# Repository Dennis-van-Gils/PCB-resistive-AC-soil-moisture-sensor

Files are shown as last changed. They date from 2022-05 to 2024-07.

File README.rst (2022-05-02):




Resistive AC soil moisture sensor
=================================

This project involves a printed circuit board design to measure the resistance
between two metallic probes that can be placed inside soil as a measure of the
soil humidity. It uses AC current to sense the resistance between the probes,
preventing corrosion of the probes which otherwise would happen when a DC
current is used instead. The design is based on the
`SMX sensor <https://www.emesystems.com/smx/main.html>`__ by EME Systems.

The sensor can be supplied with either 3.3 V or 5.0 V and utilizes an onboard
3.0 V regulator powering a TLC555 timer. The output is a pulse train with an
amplitude equal to the supply voltage and of a variable frequency that
correlates to the measured resistance. The pulses are at a 50% duty cycle.

Contains EAGLE, Fusion360 and LTSpice project files.

- Github: https://github.com/Dennis-van-Gils/PCB-resistive-AC-soil-moisture-sensor

PCB design
==========

The PCB production Gerber files can be found `here. <EAGLE/AC_soil_sensor_v1.0_2022-05-01.zip>`__

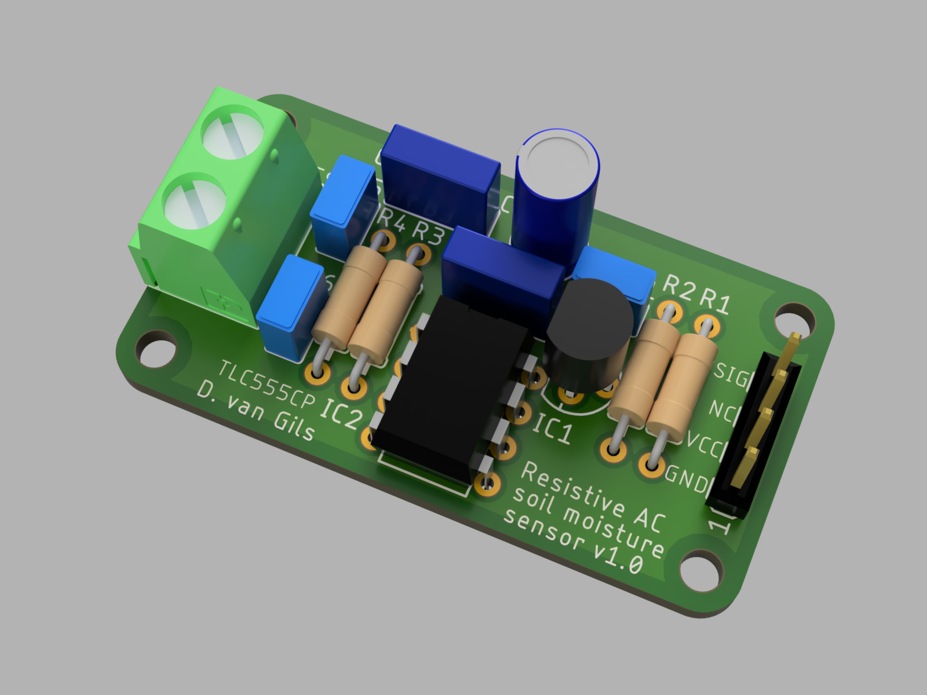
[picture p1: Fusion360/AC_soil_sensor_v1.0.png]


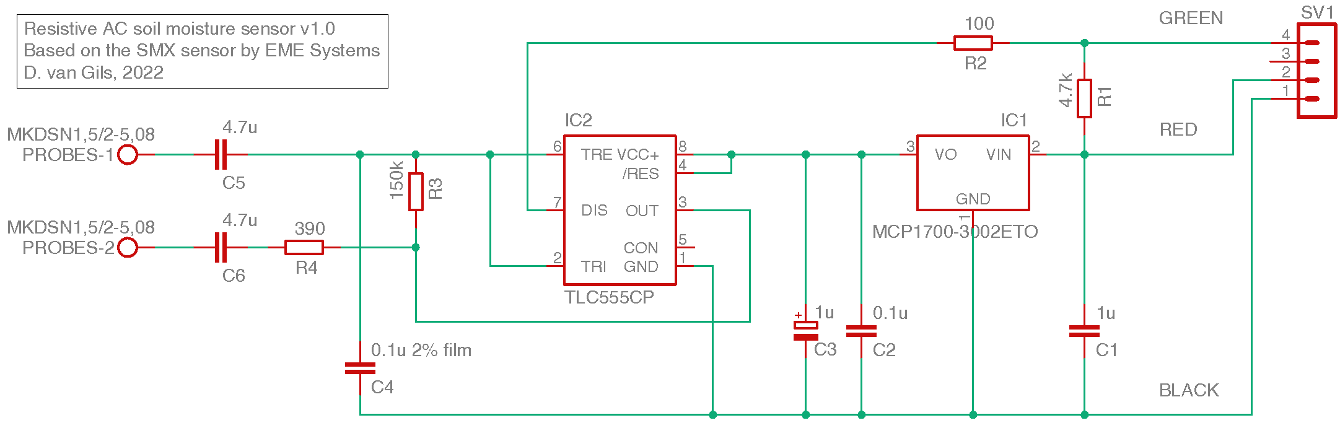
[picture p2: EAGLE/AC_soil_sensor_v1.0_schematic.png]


Bill of materials
=================

+-----+-------------------+--------------------------------------+------------------------------------+
| IC1 | CMOS low-dropout voltage regulator, 3.0V 250mA           | MCP1700-3002E/TO                   |
+-----+-------------------+--------------------------------------+------------------------------------+
| IC2 | CMOS 555 timer, input 2V-15V                             | TLC555CP                           |
+-----+-------------------+--------------------------------------+------------------------------------+
| R1  | 4.7 kΩ  1/4W   5% | Resistor, carbon film                |                                    |
+-----+-------------------+--------------------------------------+------------------------------------+
| R2  | 100  Ω  1/4W   5% | Resistor, carbon film                |                                    |
+-----+-------------------+--------------------------------------+------------------------------------+
| R3  | 150 kΩ  1/4W   5% | Resistor, carbon film                |                                    |
+-----+-------------------+--------------------------------------+------------------------------------+
| R4  | 390  Ω  1/4W   5% | Resistor, carbon film                |                                    |
+-----+-------------------+--------------------------------------+------------------------------------+
| C1  | 1   μF   50V  10% | Capacitor, ceramic                   | KEMET C320C105K5N5TA91707301       |
+-----+-------------------+--------------------------------------+------------------------------------+
| C2  | 0.1 μF   50V  10% | Capacitor, ceramic                   | KEMET C320C104K5R5TA7301           |
+-----+-------------------+--------------------------------------+------------------------------------+
| C3  | 1   μF   50V      | Capacitor, aluminium electrolytic    |                                    |
+-----+-------------------+--------------------------------------+------------------------------------+
| C4  | 0.1 μF   63V   5% | Capacitor, metallized polyester film | TDK B32529C0104J                   |
+-----+-------------------+--------------------------------------+------------------------------------+
| C5  | 4.7 μF   25V  10% | Capacitor, ceramic                   | KEMET C320C475K3N5TA91707301       |
+-----+-------------------+--------------------------------------+------------------------------------+
| C6  | 4.7 μF   25V  10% | Capacitor, ceramic                   | KEMET C320C475K3N5TA91707301       |
+-----+-------------------+--------------------------------------+------------------------------------+

LTspice simulation
==================

The frequency-resistance relationship of the simulated idealized circuit:

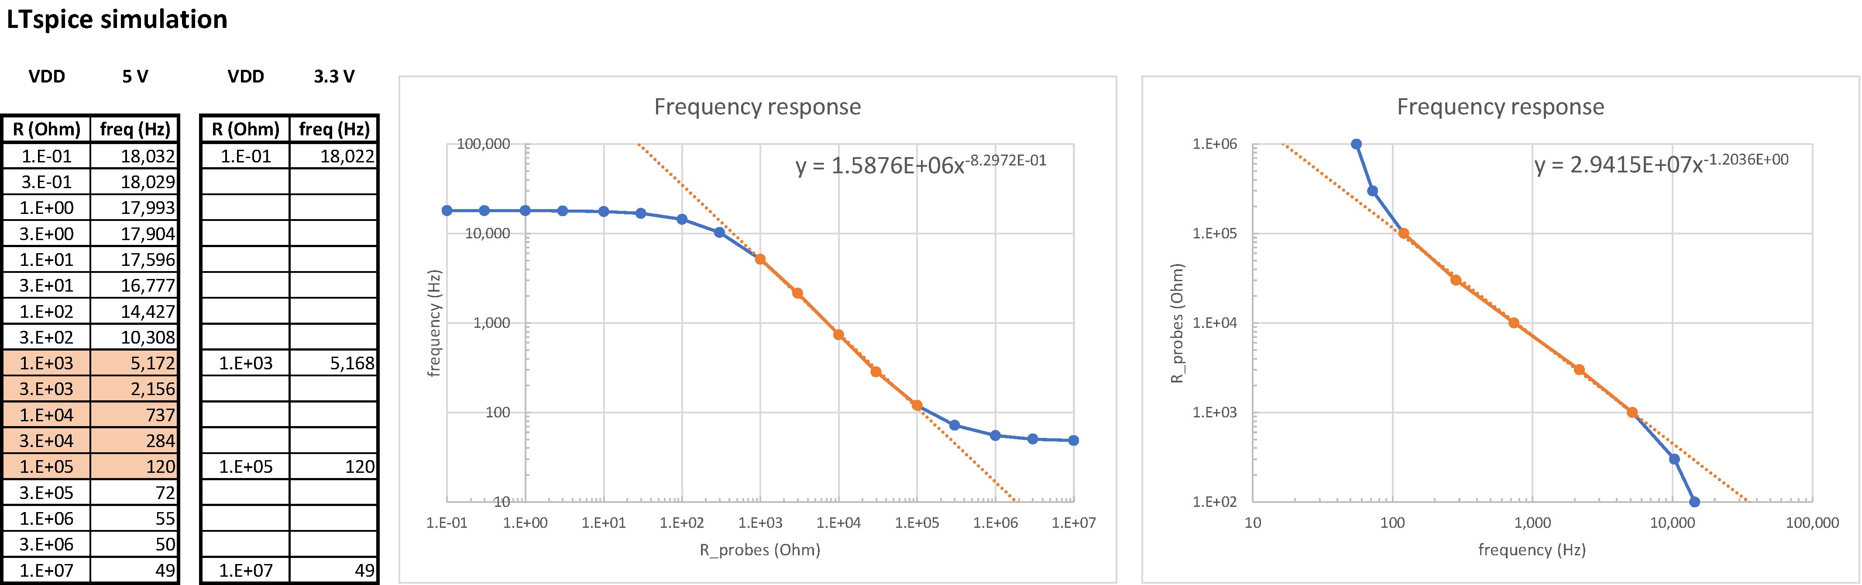
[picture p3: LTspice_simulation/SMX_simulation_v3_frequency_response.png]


Dennis van Gils, 2022

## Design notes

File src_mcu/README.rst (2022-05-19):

Demo C++ source code to be flashed onto a microcontroller board:

Minimum working example to measure a frequency on a digital input pin using
an interrupt service routine and with averaging applied to the frequency
measurement.

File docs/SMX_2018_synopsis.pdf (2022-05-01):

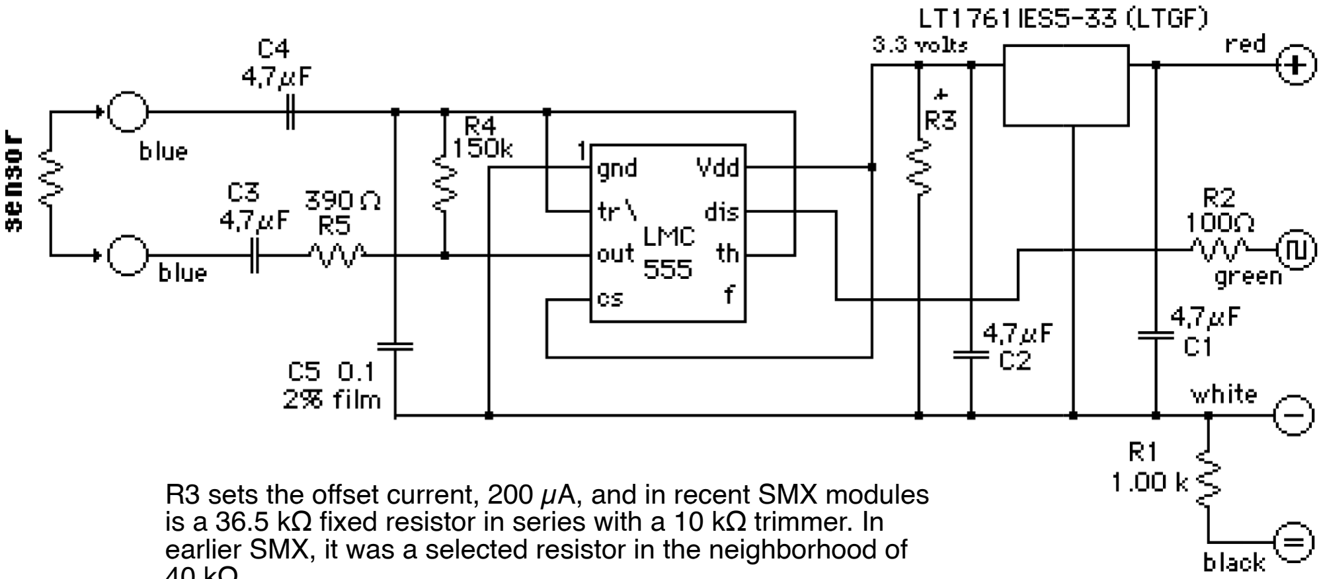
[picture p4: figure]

R3 sets the offset current, 200 µA, and in recent SMX modules is a 36.5 kΩ fixed resistor in series with a 10 kΩ trimmer. In earlier SMX, it was a selected resistor in the neighborhood of 40 kΩ.

The power supply voltage is regulated at 3.3 volts DC by the micropower regulator. The power supply + input can be as low as 4 volts and as high as 15 volts. Filter capacitors are provided for stability and averaging of the supply current. The LMC555 timer operates in its direct feedback mode, with a square wave on the totem pole output from pin 3 charging or discharging the 0.1 µF polyester film timing capacitor through the network of fixed resistors in series/parallel with the moisture sensor. When the sensor is dry, the 150 kΩ resistor sets a minimum oscillator frequency of 50 hertz. When the sensor is wet, or a short circuit, the 390 Ω in series with the grid limits the upper frequency to about 13 kHz. The current through the sensing grid is AC. Nonpolar ceramic capacitors isolate the circuit from the sensor, to assure that the average current is AC and to forestall galvanic interactions in the soil environment. The output frequency is transmitted to the logger from the open collector DIS output pin, protected from miswiring by the 100 Ω resistor. Normally a pullup resistor will be provided to give voltage transitions at the logger. The current drawn by the circuit varies linearly with the frequency due to the charge and discharge cycles of the 0.1 µF capacitor. The supply current is proportional to wetness, a voltage signal can be taken from across the 1kΩ resistor. The offset current is set to 200 µA by R3, 36.5 kΩ in series with 10 kΩ trimmer.
There will be a small AC component on the DC output signal, that can be averaged in software. A 10 µF capacitor in parallel with the output resistor will reduce the AC component to <5 millivolts.

black

white | frequency output
| common

3.3 – 15 V
red | 0.2 – 1 mA
green

4.7 kΩ

sensor

SMX

I. Digital frequency output: 50 – 10,000 Hz.

black

white

voltage signal (+)
0.2 – 1 V DC

common

4.5 – 15 V
red | 0.2 – 1 mA

100 µF

sensor

SMX | green

II. Voltage output: 0.2 – 1 V.

black

white

voltage signal (+)
Vout = I * R

common

4.5 – 15 V
red | 0.2 – 1 mA

22 µF

0.2 ~ 1 mA

sensor

green

R

SMX

III. Two wire current output: 0.2 – 1 mA.

The current on the two wire circuit may be converted to a voltage at the input of the data logger. A 1 kΩ resistor will convert the 0.2 – 1 mA current into a 0.2 – 1 V signal.

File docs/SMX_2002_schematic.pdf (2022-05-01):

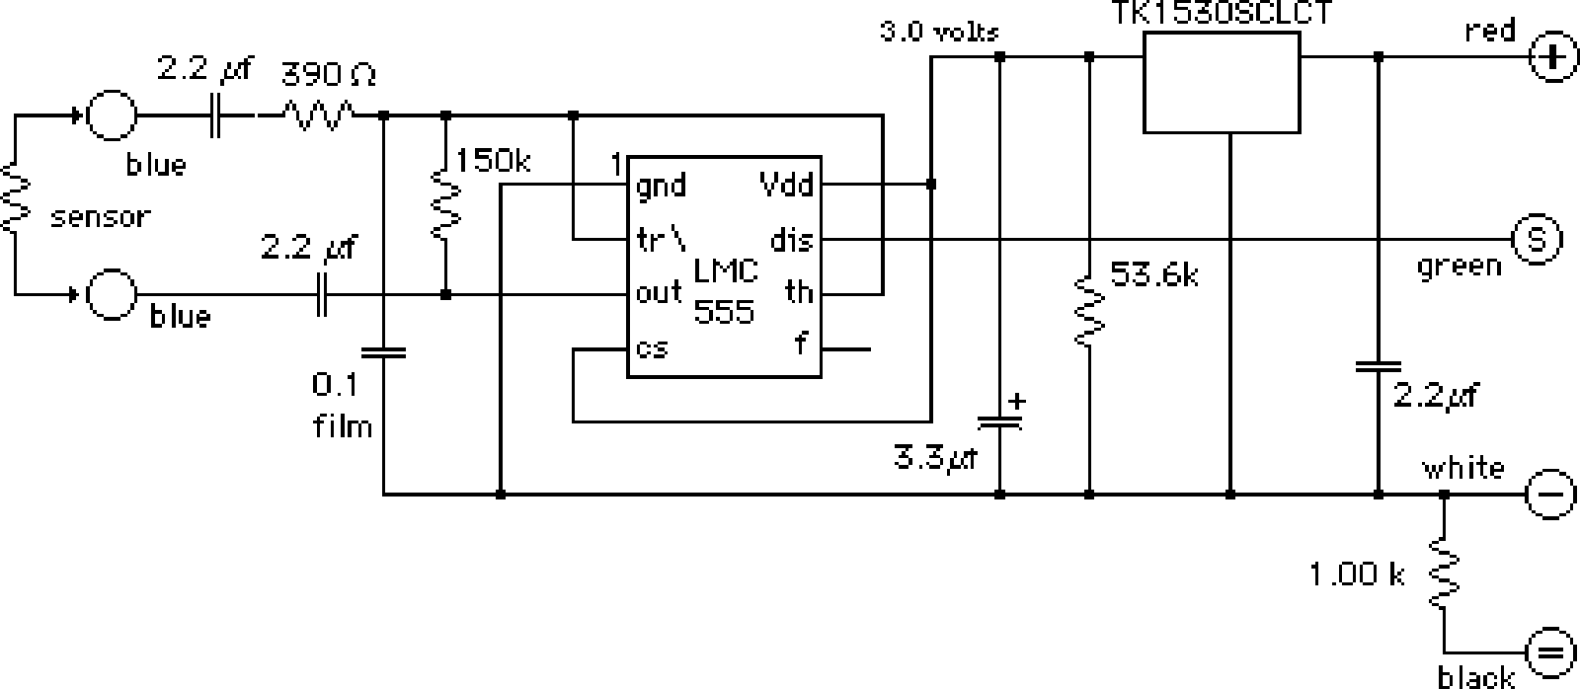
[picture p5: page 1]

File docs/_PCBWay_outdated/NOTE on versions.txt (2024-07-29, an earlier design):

Notes:
* Even though the board in this folder is called v2, it is not. It is an alpha version. Alpha 2.0 that is. The version in the folder one up is labelled 1, as in release 1.0.
* v2d v18 equals v2f

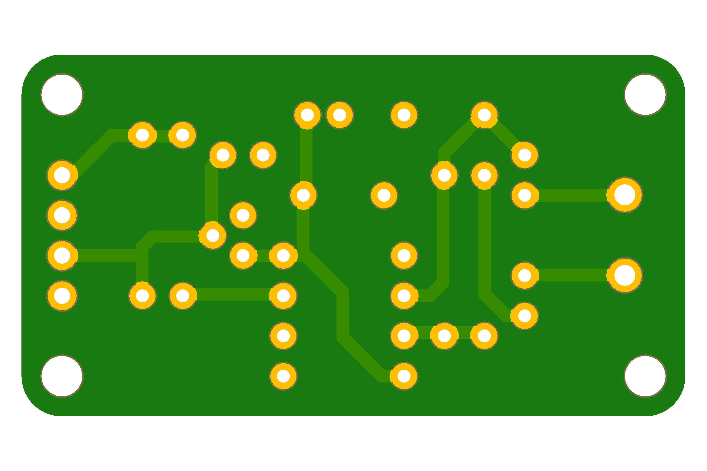
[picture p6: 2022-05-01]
EAGLE/AC_soil_sensor_v1.0_bottom.png

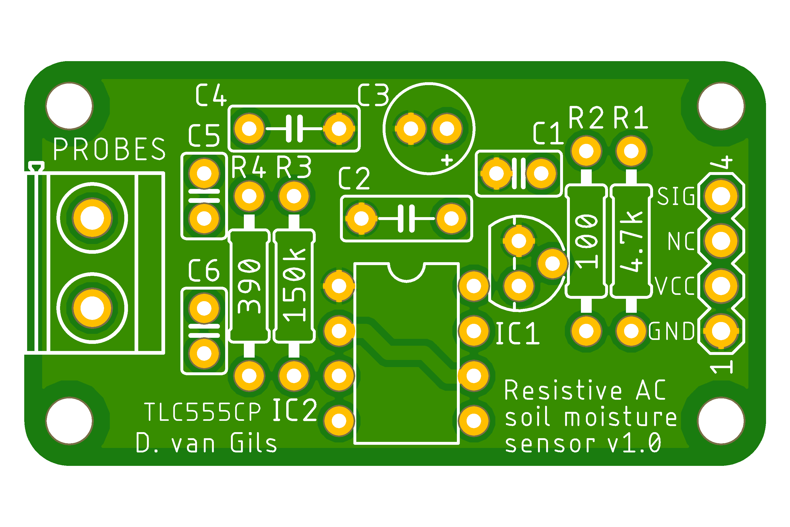
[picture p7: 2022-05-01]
EAGLE/AC_soil_sensor_v1.0_top.png

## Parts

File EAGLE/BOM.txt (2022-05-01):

Bill of materials: `Resistive AC soil moisture sensor v1.0`

IC1   MCP1700-3002E/TO     CMOS low dropout voltage regulator, output 3.0V 250mA, input 2.3V-6.0V
IC2   TLC555CP             CMOS 555 timer, input 2V-15 V
R1    4.7 kΩ  1/4W   5%    Resistor, carbon film
R2    100  Ω  1/4W   5%    Resistor, carbon film
R3    150 kΩ  1/4W   5%    Resistor, carbon film
R4    390  Ω  1/4W   5%    Resistor, carbon film
C1    1   μF   50V  10%    Capacitor, ceramic                     KEMET C320C105K5N5TA91707301
C2    0.1 μF   50V  10%    Capacitor, ceramic                     KEMET C320C104K5R5TA7301
C3    1   μF   50V         Capacitor, aluminium electrolytic
C4    0.1 μF   63V   5%    Capacitor, metallized polyester film   TDK B32529C0104J
C5    4.7 μF   25V  10%    Capacitor, ceramic                     KEMET C320C475K3N5TA91707301
C6    4.7 μF   25V  10%    Capacitor, ceramic                     KEMET C320C475K3N5TA91707301

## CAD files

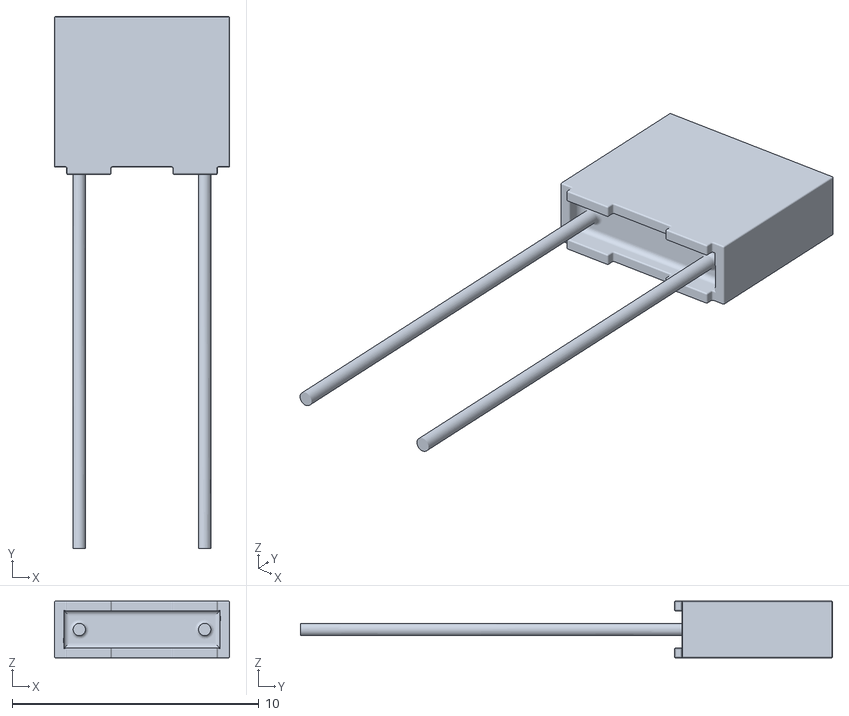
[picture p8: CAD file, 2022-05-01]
Fusion360/3D_parts/47nF Film Capacitor MKT.STL
7.10 x 21.6 x 2.30

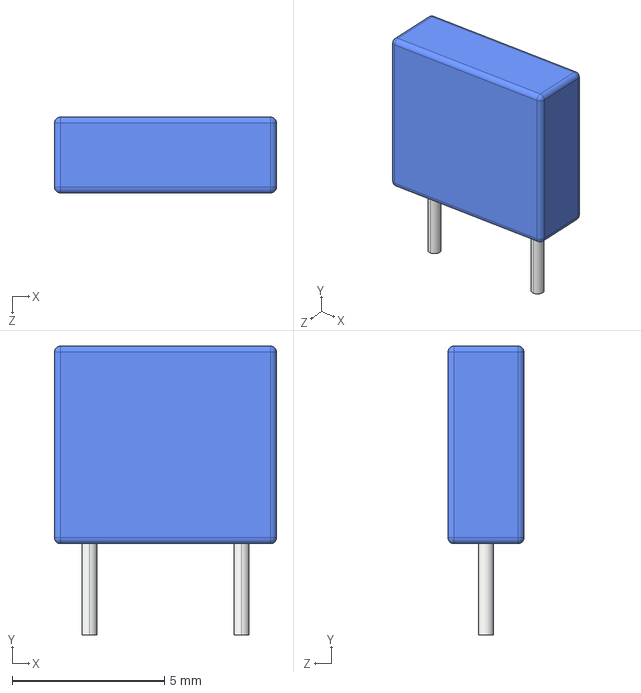
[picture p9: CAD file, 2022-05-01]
Fusion360/3D_parts/film_capacitor_2.5_7.3.STEP
7.30 x 9.50 x 2.50 mm

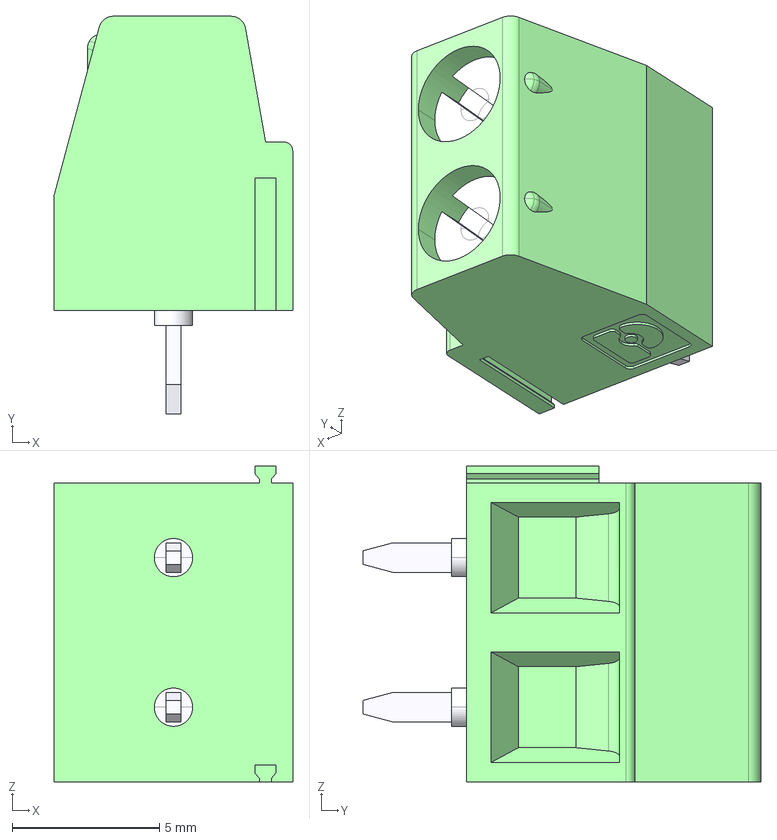
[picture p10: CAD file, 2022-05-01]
Fusion360/3D_parts/pxc_1729128_07_MKDSN-1-5-2-5-08_3D.stp
8.10 x 13.5 x 10.7 mm

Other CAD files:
Fusion360/3D_parts/film_capacitor_2.5_7.3.SLDPRT
Fusion360/AC_soil_sensor_v1.0.f3d
docs/_PCBWay_outdated/resistive_AC_soil_moisture_sensor_v2d v18.f3d

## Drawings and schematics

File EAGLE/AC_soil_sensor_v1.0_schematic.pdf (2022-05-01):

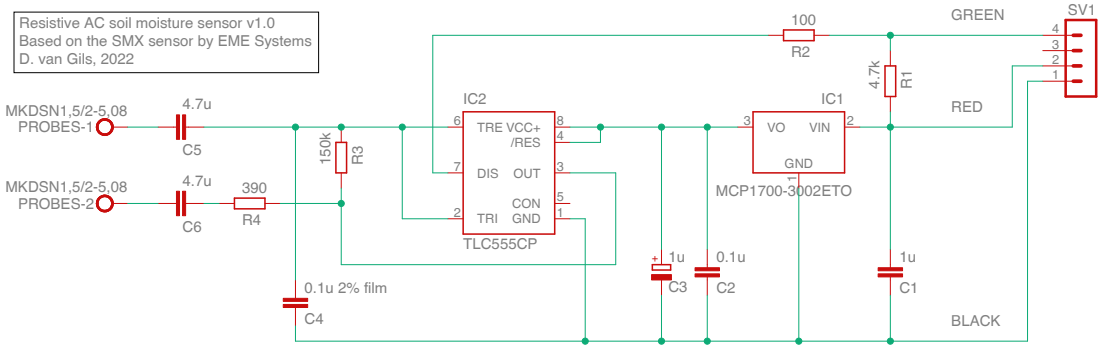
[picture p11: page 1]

Resistive AC soil moisture sensor v1.0
Based on the SMX sensor by EME Systems
D. van Gils, 2022 BES-1 PROBES-2

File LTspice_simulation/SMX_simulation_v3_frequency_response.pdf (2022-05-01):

## LTspice simulation

## Frequency response

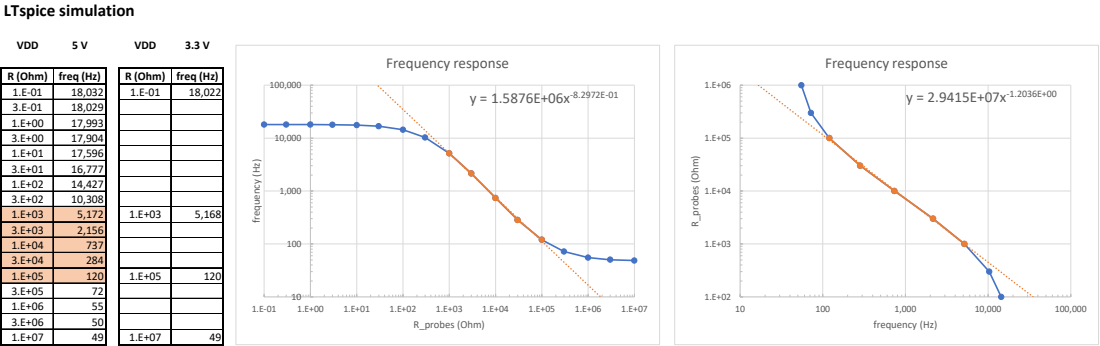
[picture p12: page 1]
VDD; R (Ohm); freq (Hz); 1.E+07 frequency ⁽Hz⁾; R_probes (Ohm); frequency (Hz); Frequency response

3.E-01 | 18,029
1.E+00 | 17,993
3.E+00 | 17,904
1.E+01 | 17,596
3.E+01 | 16,777
1.E+02 | 14,427
3.E+02 | 10,308

3.E+03 | 2,156
1.E+04 | 737
3.E+04 | 284

3.E+05 | 72
1.E+06 | 55
3.E+06 | 50

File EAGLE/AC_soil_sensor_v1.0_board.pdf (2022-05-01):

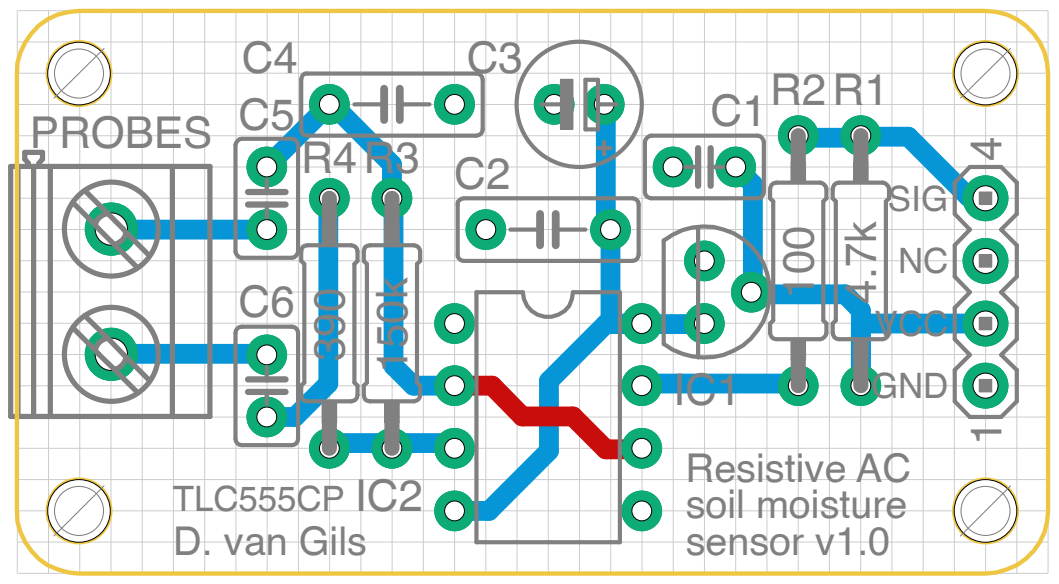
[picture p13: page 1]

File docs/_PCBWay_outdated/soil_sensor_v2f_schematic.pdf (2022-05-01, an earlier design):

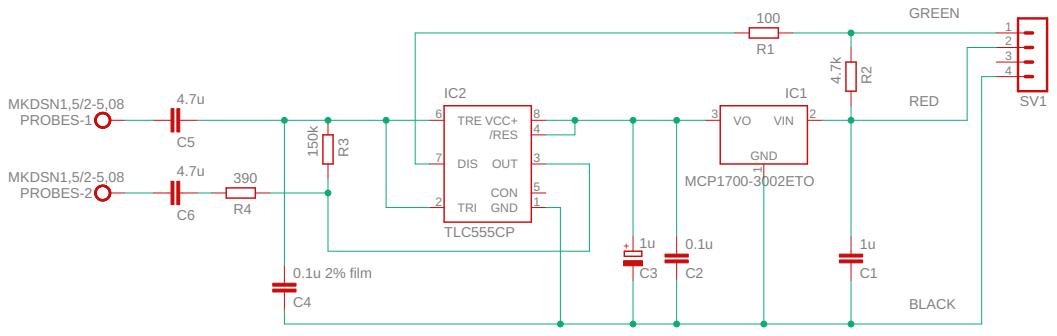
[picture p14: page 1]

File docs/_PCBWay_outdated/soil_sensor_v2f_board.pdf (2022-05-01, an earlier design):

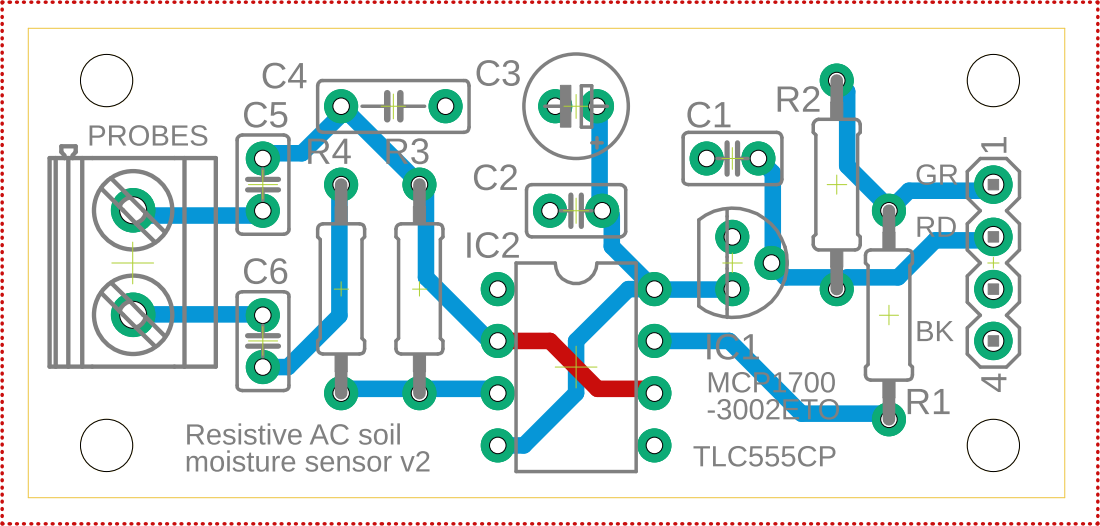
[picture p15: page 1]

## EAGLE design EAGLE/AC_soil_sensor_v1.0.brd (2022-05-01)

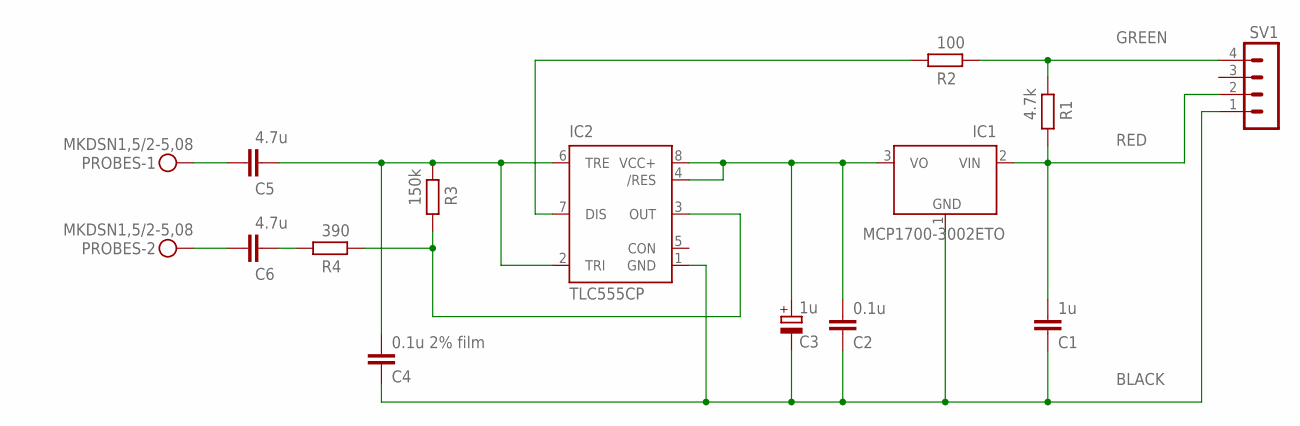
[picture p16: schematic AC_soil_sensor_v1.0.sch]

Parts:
C1: 1u; C025-025X050
C2: 0.1u; C050-025X075
C3: 1u; E2-5
C4: 0.1u 2% film; C050-025X075
C5, C6: 4.7u; C025-025X050
IC1: MCP1700-3002ETO; TO92
IC2: TLC555CP; DIL-08
PROBES: MKDSN1,5/2-5,08
R1: 4.7k; 0207/10
R2: 100; 0207/10
R3: 150k; 0207/10
R4: 390; 0207/10
SV1: MA04-1

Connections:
BLACK: C1.1, C2.2, C3.-, C4.2, IC1.1 (GND), IC2.1 (GND), SV1.1
GREEN: R1.2, R2.1, SV1.4
unnamed: C4.1, C5.2, IC2.2 (TRI), IC2.6 (TRE), R3.2
unnamed: C6.2, R4.1
unnamed: C5.1, PROBES.1
unnamed: C2.1, C3.+, IC1.3 (VO), IC2.4 (/RES), IC2.8 (VCC+)
unnamed: IC2.3 (OUT), R3.1, R4.2
unnamed: IC2.7 (DIS), R2.2
unnamed: C6.1, PROBES.2
RED: C1.2, IC1.2 (VIN), R1.1, SV1.2

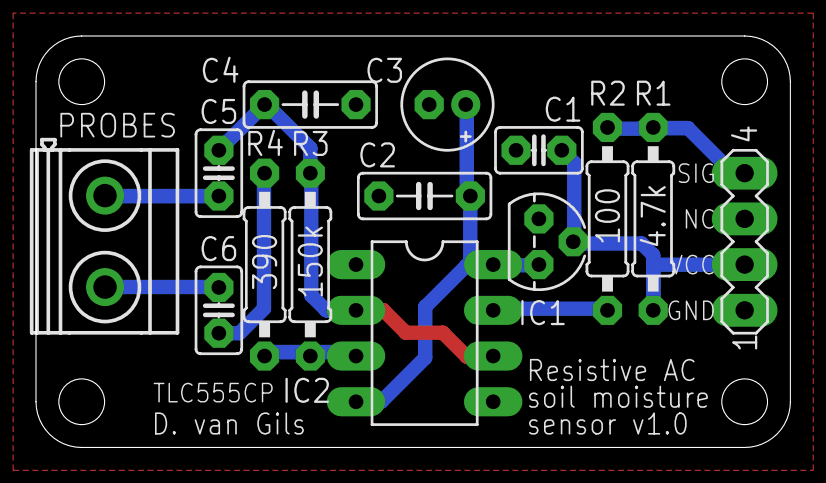
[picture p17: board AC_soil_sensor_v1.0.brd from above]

Board: 2 copper layers, 41.9 x 22.9 mm, 14 parts (0 on the bottom side), 10 nets.

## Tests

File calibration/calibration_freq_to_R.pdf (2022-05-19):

## calibration_freq_to_R

May 19, 2022

## 1 Calibration: frequency to resistance

### 1.1 Hardware used

A | single | build | Resistive AC soil moisture sensor v1.0 | PCB | connected | to | an
Adafruit ItsyBitsy 32u4 microcontroller board flashed with the following code found at: https://github.com/Dennis-van-Gils/PCB-resistive-AC-soil-moisture-sensor/tree/main/src_mcu

### 1.2 Calibration procedure

I apply a known resistance R[Ohm] over the probe terminals and measure the resulting frequency f[Hz]. I then perform a non-linear least-squares fit to the data to be able to transform the output frequency back to a resistance.

### 1.3 Used fit

The log10(f) vs log10(R) curve can be captured by an S-curve rotated by 90 degrees, also known as a logit function (https://en.wikipedia.org/wiki/Logit):

logit(p) = ln(p / (1 - p)), for 0 < p < 1

I add 4 fitting parameters k, x0, b and a to the logit function to be able to fit the data. Hence, what we end up with is the following C++ code to transform measured frequency [Hz] into resistance [Ohm]:

double p = (log10(frequency) - x0) * b;
double R_log = (k * log(p / (1 - p)) + a);
resistance = pow(10, R_log);

The fit is inherently monotonic.

### 1.4 Calibration results

In this specific realization I found the following best fit results, leading to a resistance fitting accuracy of +/-20 % (at worst). It is good enough for order-of-10s estimation over the range 10 Ohm to 10 MOhm.

const double k = -0.61404261;
const double x0 = 1.65479988;
const double b = 0.40044114; const double a = 3.97842502;

Dennis van Gils, 19-05-2022

[1]: import numpy as np
import matplotlib.pyplot as plt

# Applied a known resistance R[Ohm] and measured the resulting frequency f[Hz] R = np.array([0.1, 10, 33, 100, 330, 1000, 3300, 10000, 33000, 100000, 330000,␣ ↪1200000, 100000000])

f = np.array([13755, 13513, 12987, 11600, 8554, 4873, 1955, 734, 265, 120, 70,␣ ↪54, 48])

# Fit becomes better when we remove the outer points

R = R[1:-1]
f = f[1:-1]

# Plot

R_log = np.log10(R)
f_log = np.log10(f)
plt.plot(f_log, R_log, 'x-') plt.xlabel('log10 frequency [Hz]') plt.ylabel('log10 resistance [Ohm]') plt.grid()
plt.show()

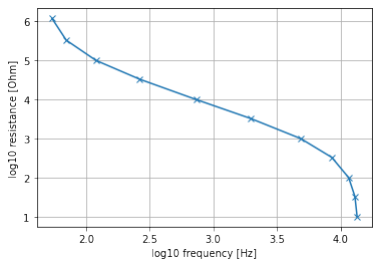
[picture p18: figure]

[2]: def logit_fun(x, k, x0, b, a): # The log10(frequency)-log10(resistance) curve can be captured by # a `logit()` function, where
# logit(p) = ln(p / (1 - p)), for 0 < p < 1

p = (x - x0) * b
p = list(map(lambda x: np.nan if ((x <= 0) or (x >= 1)) else x, p)) p = np.array(p)
return (k * np.log(p / (1 - p)) + a)

# Manually search for a reasonable fit to act as an initial guess

# for the upcoming non-linear least-squares fitting procedure p0 = [-0.7, 1.68, 0.4, 4] # Initial guess

x = np.linspace(1.7, 4.14, 501)
y = logit_fun(x, *p0)

plt.plot(x, y, 'r')
plt.plot(f_log, R_log, 'x-') plt.title('initial guess') plt.xlabel('log10 frequency [Hz]') plt.ylabel('log10 resistance [Ohm]') plt.grid()
plt.show()

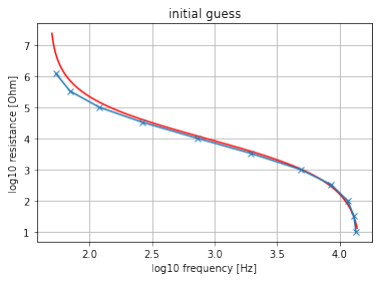
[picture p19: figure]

[3]: # Non-linear least-squares fitting
from scipy.optimize import curve_fit
popt, pcov = curve_fit(logit_fun, f_log, R_log, p0, method='lm') print(popt) # Optimal best-fit result: [k, x0, b, a]

[-0.61404261 1.65479988 0.40044114 3.97842502]

[4]: y_fit = logit_fun(x, *popt)
plt.plot(x, y_fit, 'r')
plt.plot(f_log, R_log, 'x-')
plt.title('best fit')
plt.xlabel('log10 frequency [Hz]') plt.ylabel('log10 resistance [Ohm]') plt.grid()
plt.show()

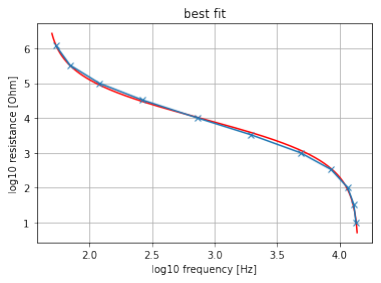
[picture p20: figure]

[5]: # Show fitting residuals and deviation
R_fit = 10**(logit_fun(f_log, *popt))
R_residuals = R_fit - R

print("%8s%12s%12s%10s%9s" % ("f [Hz]", "R [Ω]", "R_fit [Ω]", "res [Ω]", "dev␣ ↪[%]"))
for idx, value in enumerate(R_fit):

print("%8.0f%12.0f%12.0f%10.0f%9.0f" % (f[idx], R[idx], R_fit[idx],␣ ↪R_residuals[idx], R_residuals[idx]/R[idx]*100))

f [Hz] | R [Ω] | R_fit [Ω] | res [Ω] dev [%]
13513 | 10 | 11 | 1 | 14
12987 | 33 | 27 | -6 | -19
11600 | 100 | 88 | -12 | -12
8554 | 330 | 349 | 19 | 6
4873 | 1000 | 1179 | 179 | 18
1955 | 3300 | 3838 | 538 | 16
734 | 10000 | 10364 | 364 | 4
265 | 33000 | 29943 | -3057 | -9
120 | 100000 | 89605 | -10395 | -10
70 | 330000 | 323978 | -6022 | -2
54 | 1200000 | 1232152 | 32152 | 3

[ ]:

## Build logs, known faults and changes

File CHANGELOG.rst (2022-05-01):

Changelog
=========

1.0.0 (2022-05-01)
------------------
* Initial release

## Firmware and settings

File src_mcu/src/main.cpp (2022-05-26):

/*******************************************************************************
  Minimum working example to measure a frequency on a digital input pin using
  an interrupt service routine and with averaging applied to the frequency
  measurement.

  Dennis van Gils
  19-05-2022
*******************************************************************************/

#include <Arduino.h>
#include <math.h>

#define Ser Serial

// 32u4 microcontroller has interrupts on digital pins: 0, 1, 2, 3, 7
// SAMD microcontroller has interrupts on all digital pins, except 4
#ifdef _VARIANT_FEATHER_M4_
#  define PIN_SENSOR 5
#else
#  define PIN_SENSOR 7
#endif
#define N_AVG 10    // Number of up-flanks to average over
#define TIMEOUT 300 // [ms] Timeout to stop detecting the frequency

volatile bool isr_done = false;
volatile uint8_t isr_counter = 0;
volatile uint32_t T_upflanks = 0; // [us] Measured duration for N_AVG up-flanks

double frequency = 0;  // [Hz] Measured average frequency
double resistance = 0; // [Ohm] Frequency to resistance best-fit transformation
const double k = -0.61404261;
const double x0 = 1.65479988;
const double b = 0.40044114;
const double a = 3.97842502;

void isr_rising() {
  /* Interrupt service routine for when an up-flank is detected on the input pin
   */
  static uint32_t micros_start = 0;

  if (!isr_done) {
    if (isr_counter == 0) {
      micros_start = micros();
    }
    isr_counter++;
    if (isr_counter > N_AVG) {
      T_upflanks = micros() - micros_start;
      isr_done = true;
    }
  }
}

bool measure_frequency() {
  uint32_t t_0 = millis();
  isr_counter = 0;
  isr_done = false;
  while ((!isr_done) && ((millis() - t_0) < TIMEOUT)) {}

  if (isr_done) {
    // Frequency to resistance best-fit transformation (is monotonic, yeay :))
    // Resistance fit +/-20 % (at worst) wrt as measured during calibration,
    // good enough for order-of-10s estimation
    frequency = 1000000. * N_AVG / T_upflanks;
    double p = (log10(frequency) - x0) * b;
    double R_log = (k * log(p / (1 - p)) + a);
    resistance = pow(10, R_log);
    if (resistance > 10e6) {
      resistance = INFINITY;
    }
  } else {
    resistance = NAN;
  }

  return isr_done;
}

// -----------------------------------------------------------------------------
//    setup
// -----------------------------------------------------------------------------

void setup() {
  Ser.begin(9600);

  // Set to INPUT_PULLUP even though the sensor itself already has a pull-up
  // resistor onboard. Doing so will prevent floating noise on the input pin
  // leading to false frequencies when the sensor is disconnected.
  pinMode(PIN_SENSOR, INPUT_PULLUP);
  attachInterrupt(digitalPinToInterrupt(PIN_SENSOR), isr_rising, RISING);

  // Light up onboard LED pin 13
  pinMode(LED_BUILTIN, OUTPUT);
  digitalWrite(LED_BUILTIN, HIGH);
}

// -----------------------------------------------------------------------------
//    loop
// -----------------------------------------------------------------------------

void loop() {
  uint32_t now = millis();
  static uint32_t tick = now;

  if (now - tick > 500) {
    tick = now;

    if (measure_frequency()) {
      Ser.print(T_upflanks);
      Ser.print("\t");
      Ser.print(frequency);
      Ser.print("\t");
      Ser.println(resistance);
    } else {
      Ser.println("Timed out");
    }
  }
}

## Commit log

2022-05-13 Reorganize folders
    [resistive_AC_soil_moisture_sensor_v2d v18.f3d]
2022-05-13 Arduino demo
2022-05-18 Frequency to resistance best-fit transformation
2022-05-19 Added calibration results

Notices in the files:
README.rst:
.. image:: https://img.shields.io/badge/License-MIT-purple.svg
